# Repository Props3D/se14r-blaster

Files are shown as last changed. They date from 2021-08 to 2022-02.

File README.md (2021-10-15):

## se14r-blaster V0.4 - Prerelease
Product Shot - SE14R

Repository for the Star Wars SE-14r blaster from Props3D. 

Licensed under the Creative Commons - Attribution - Non-Commercial - Share Alike license. https://creativecommons.org/licenses/by-nc-sa/4.0/

***DO NOT SELL OR DISTRIBUTE MODELS OR CODE WITHOUT PERMISSION***

Note that prerelease models have been tested and work, but do not come with instructions or guarantee that everything fits together properly. If you want have feedback please post on our discord(https://discord.gg/NSfZcCfJU6) on the #project-starwars-se14r channel

## Props 3D
* Join the Props3D Discord: https://discord.gg/NSfZcCfJU6
* Follow progress on instagram: https://www.instagram.com/props3dpro/ or https://www.instagram.com/craiggulliver/
* Subscribe on Youtube: https://www.youtube.com/c/Props3D
* Download released designs: https://www.thingiverse.com/props3dpro/designs

## Electonic Components

Electronic | Components
------------ | -------------
Arduino Nano v3 | DF Player Mini with Micro SD Card
Arduino Nano v3 | DF Player Mini + 64mb Micro SD Card
PAM8302A Amp | 7 bit LED - Neopixel
Speaker Amp - PAM8302A | 7 bit LED - Neopixel (circular, NOT the ring)
40mm 2W speaker | 7mm Momentary Switch
40mm 2W speaker | 7mm momentary switch
Mini 360 DC-DC Buck Converter | Lipo 7 4v
Mini 360 DC-DC Buck Converter | Lipo 7.4v
1K Resister | DRV2605L with 8mm ERM
2 X 1K Resister | DRV2605L with 8mm ERM (Optional)

## Parts

* 4x20 pellet gun scope (ebay or aliexpress)
* M5X8mm~12mm Flat X 4 - Grips
* M4X12mm Socket X 2 - Reciever Joiner
* M4X8mm Button X 3 - Scope
* M3X6mm Button X 2 - Haptic Driver
* M3X4~8mm Button X 4 - Battery Cover
* M3X6mm Socket X 3 - Trigger switch / LED
* M3X4~8mm Grub X 5 - BarrelCap / Sight
* M4X6~8mm Grub X 6 - Magazine/Stock Bracket

## Required Libraries
There's are number of libraries that you will need to install using the Arduino Library Manager:
 1. DFPlayerMini_Fast
 2. FastLED
 4. FireTimer
 5. ezButton
 6. Adafruit_DRV2605

## Setup and Configuration
The code can be used by updating the values in config.h based on your components,
wiring, and audio tracks.

```c++   
/** 
 * Enable debug logging:
 *    enabled == 1
 *    disabled == 0
 */
#define ENABLE_DEBUG         0

// Comment out if you want to disable any component
#define ENABLE_EASY_AUDIO            1 //Enable all audio 
#define ENABLE_EASY_BUTTON           1 //Enable all buttons
#define ENABLE_EASY_HAPTIC_2605      1 //Enable haptic driver - disable if using analog
//#define ENABLE_EASY_HAPTIC_ANALOG    1 //Enable analog vibration motors - diable if using driver

// Pin configuration for MP3 Player
#define AUDIO_RX_PIN        5
#define AUDIO_TX_PIN        4

// Pin configuration for all momentary triggers
#define TRIGGER_PIN         3

// Pin for vibration motor digital pin 
#define HAPTIC_PIN          2

// Pin configuration for front barrel WS2812B 7bit LED
#define FIRE_LED_PIN        13
#define FIRE_LED_CNT        7

// track by file index - upload these to the SD card in the correct order
#define TRACK_START_UP        1
#define TRACK_CHANGE_MODE     2
#define TRACK_FIRE_A          3
#define TRACK_FIRE_B          4
#define TRACK_STUN_A          5
#define TRACK_STUN_B          6
#define TRACK_CLIP_RELOAD     7
#define TRACK_CLIP_EMPTY      8
#define TRACK_THEME           9
```

## Audio File Setup
The DF Mini Player will play back both mp3 and wav files. However, the program play
back tracks based on index. The index is determined by the order the files are loaded
onto the card. It also expects all files to be loaded into a sub directory on the card
called "/mp3".

When using a MAC to load files, it will create hidden files that will cause the playback
to seem like it's not working. You'll need to use the terminal window to rm all of these
files and directories from the card.

## Example Wiring Diagram:
SampleWiring

## Test Board Reference Design
SE14r

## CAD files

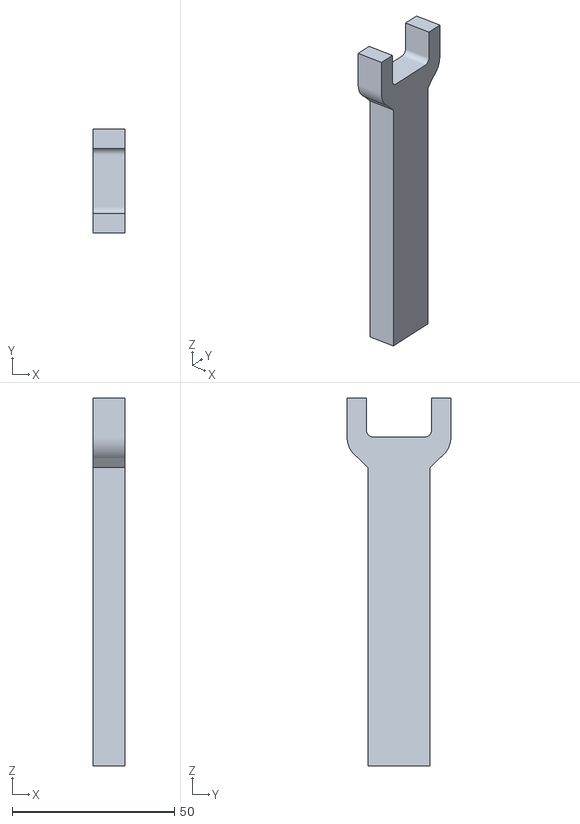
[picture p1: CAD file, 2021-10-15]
models/SE-14r_StandPostBack_V4.stl
10.00 x 32.0 x 113.5

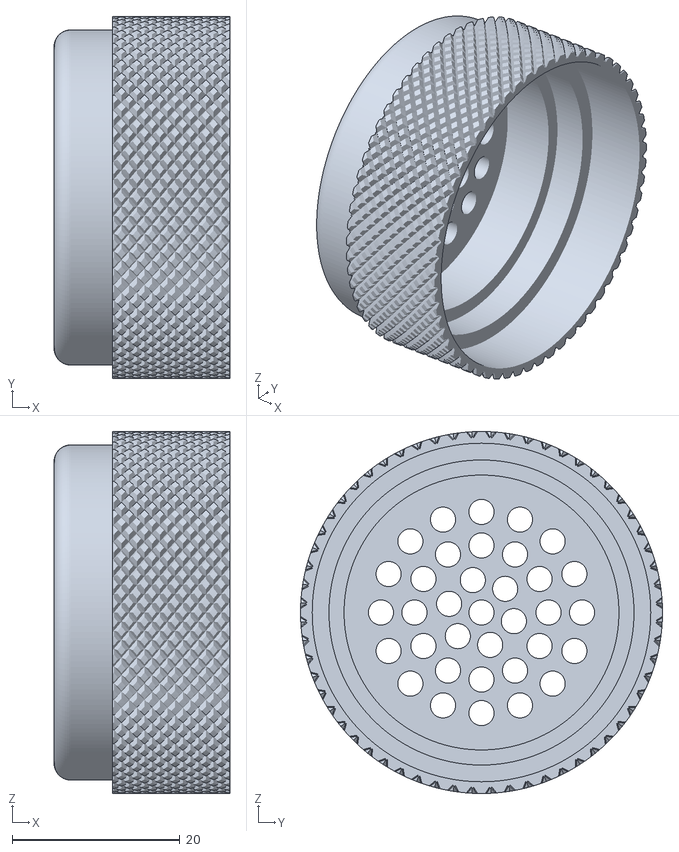
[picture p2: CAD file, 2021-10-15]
models/SE-14r_CapRearOuter_V4.stl
21.0 x 43.2 x 43.2

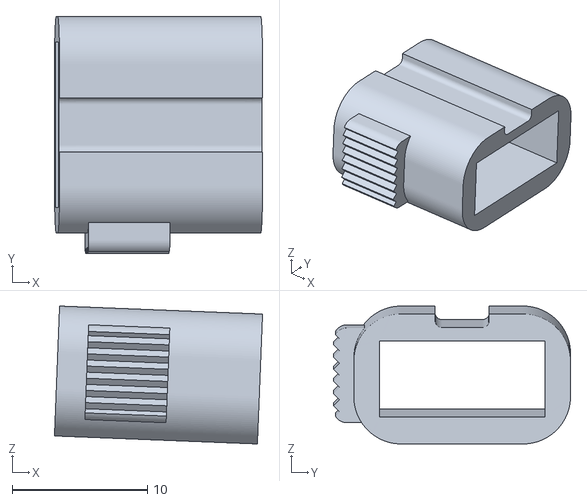
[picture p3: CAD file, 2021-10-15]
models/SE-14r_SightTop_Adjust_V4.stl
15.4 x 17.5 x 10.2

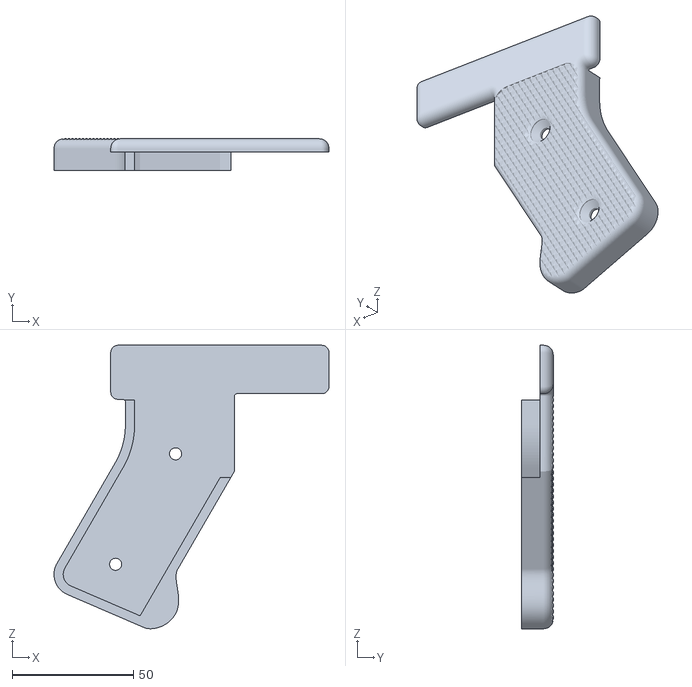
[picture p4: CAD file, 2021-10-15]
models/SE-14r_GripL_V4.stl
113.4 x 13.0 x 116.9

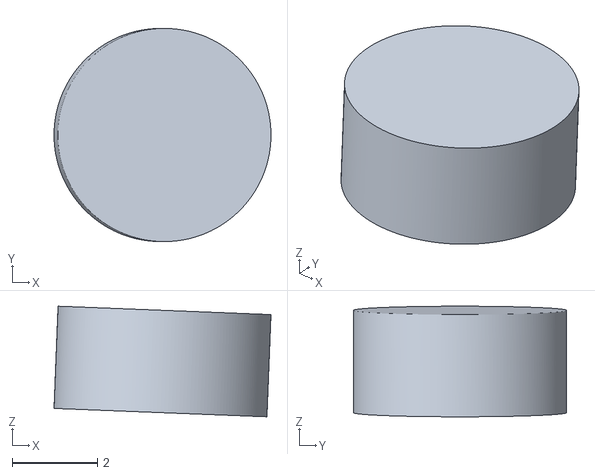
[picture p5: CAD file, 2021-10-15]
models/SE-14r_SightTop_Retainer_V4.stl
5.09 x 5.00 x 2.60

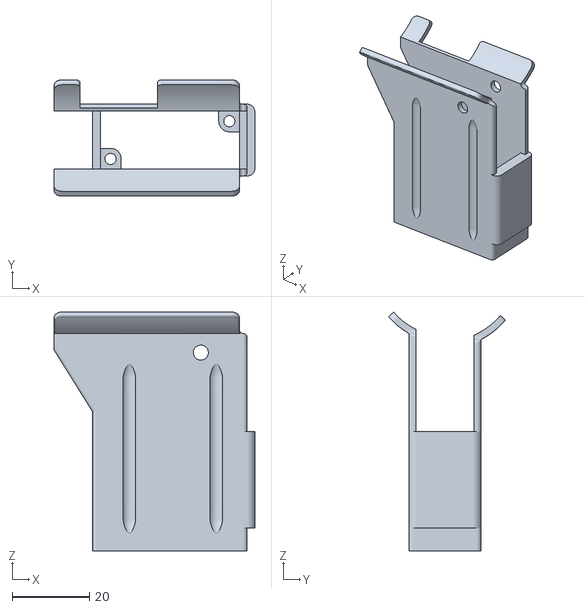
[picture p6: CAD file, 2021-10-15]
models/SE-14r_Magazine_V4.stl
52.0 x 30.1 x 61.9

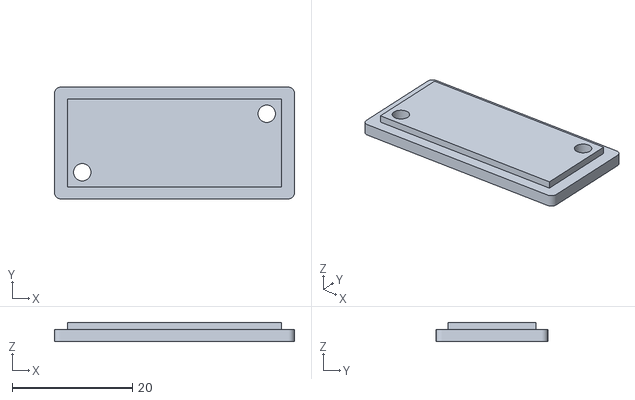
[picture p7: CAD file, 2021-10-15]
models/SE-14r_BatteryCover_V4.stl
40.0 x 18.6 x 3.20

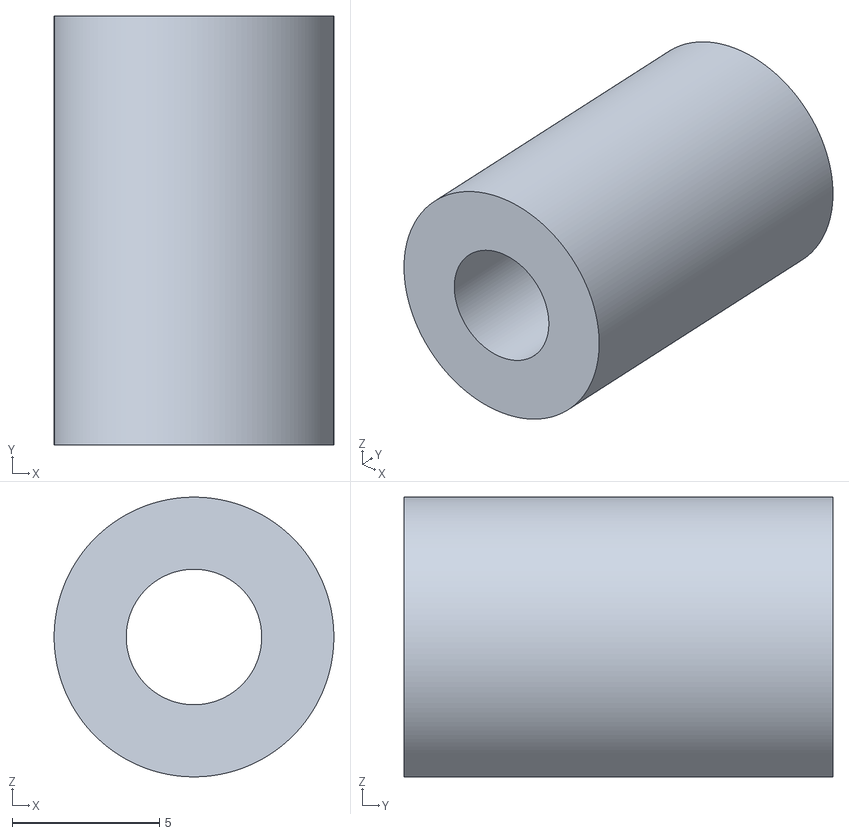
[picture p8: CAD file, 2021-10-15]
models/SE-14r_GripJoiner_V4.stl
9.50 x 14.6 x 9.50

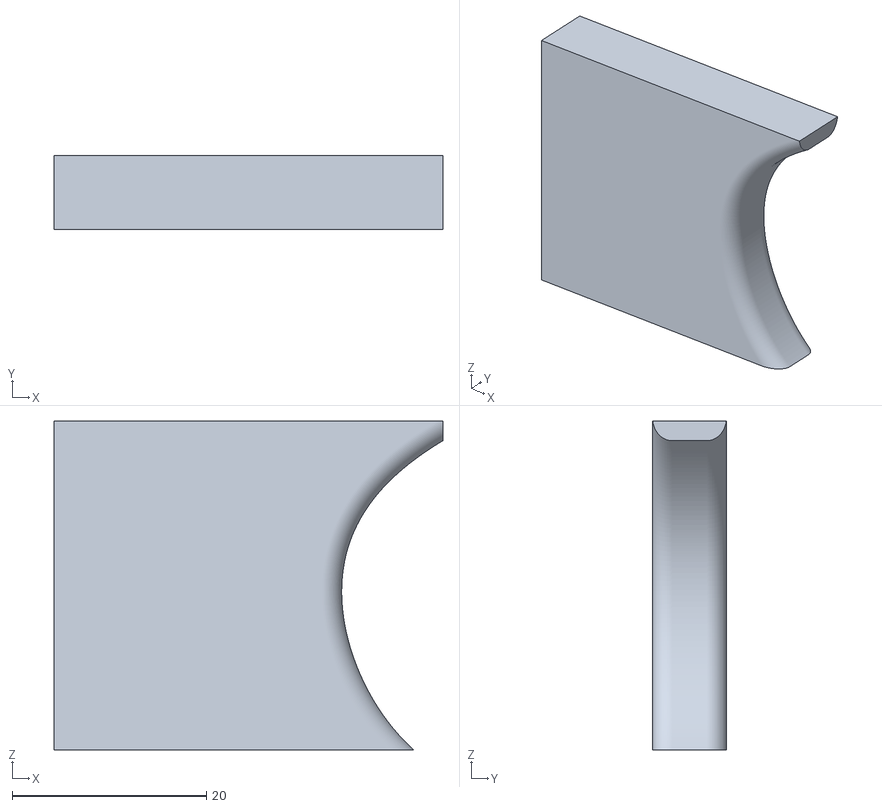
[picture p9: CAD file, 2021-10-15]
models/SE-14r_Trigger_V4.stl
40.0 x 7.60 x 33.8

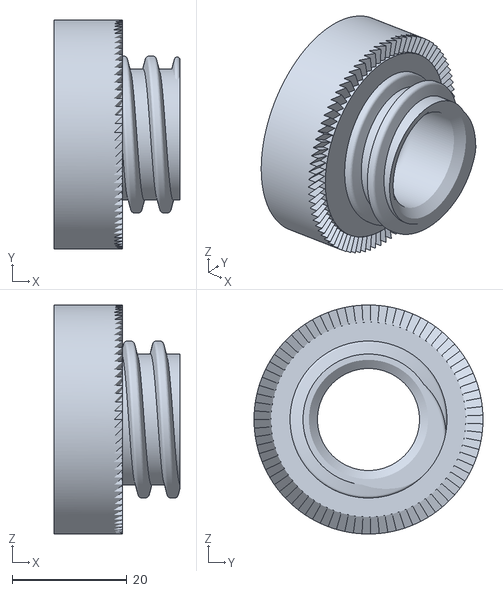
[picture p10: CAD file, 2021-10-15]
models/SE-14r_CapRearInner_V4.stl
22.0 x 40.0 x 40.0

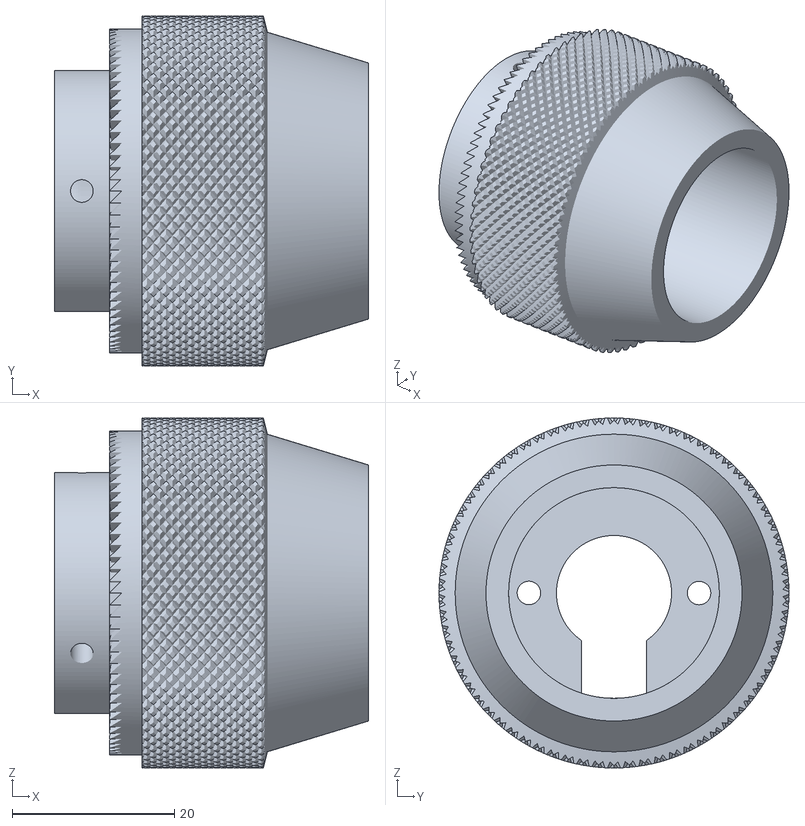
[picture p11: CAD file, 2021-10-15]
models/SE-14r_CapFront_V4.stl
38.8 x 43.2 x 43.2

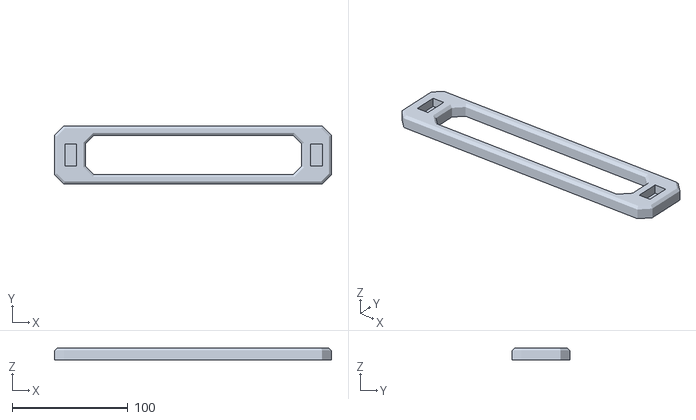
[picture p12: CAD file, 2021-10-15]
models/SE-14r_StandBase_V4.stl
239.6 x 50.0 x 10.0

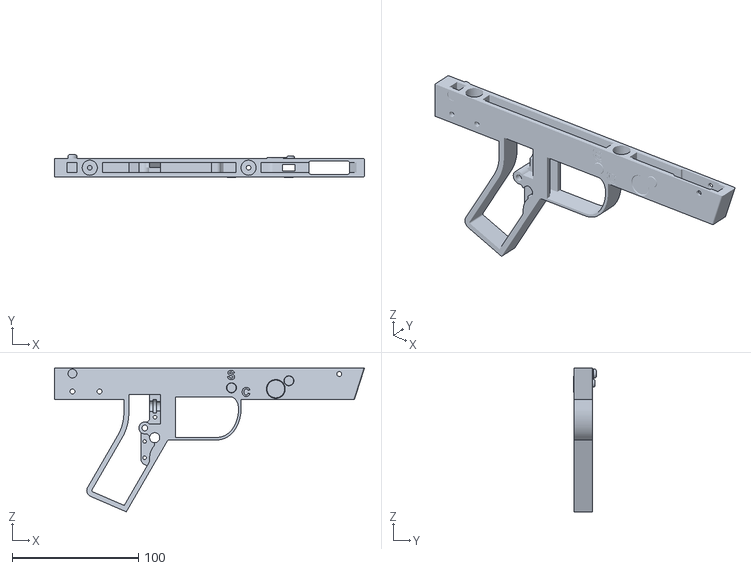
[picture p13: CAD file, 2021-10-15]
models/SE-14r_Lower_V4.stl
246.0 x 17.9 x 114.0

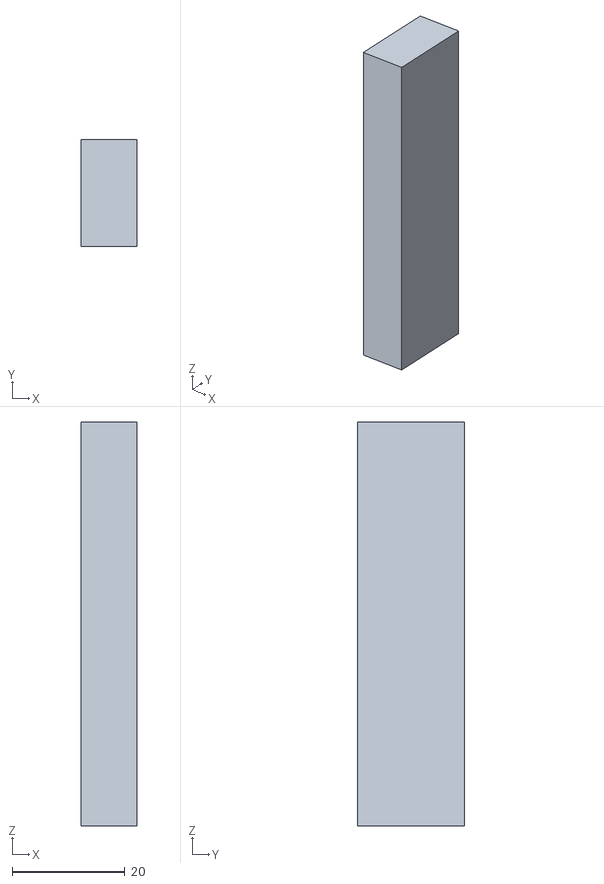
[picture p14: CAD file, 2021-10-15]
models/SE-14r_StandPostFront_V4.stl
10.0 x 19.0 x 71.8

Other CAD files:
models/SE-14r_ScopeMount_V4.stl
models/SE-14r_GripR_V4.stl
models/SE-14r_UpperBack_V4.stl
models/SE-14r_UpperFront_V4.stl
models/SE-14r_BoltHandle_V4.stl
models/SE-14r_Bolt_V4.stl
models/SE-14r_Selector_V4.stl
models/SE-14r_SightBottom_V4.stl
models/SE-14r_SightTop_V4.stl
models/SE-14r_StockBracket_V4.stl
models/SE-14r_SwitchHolder_V4.stl

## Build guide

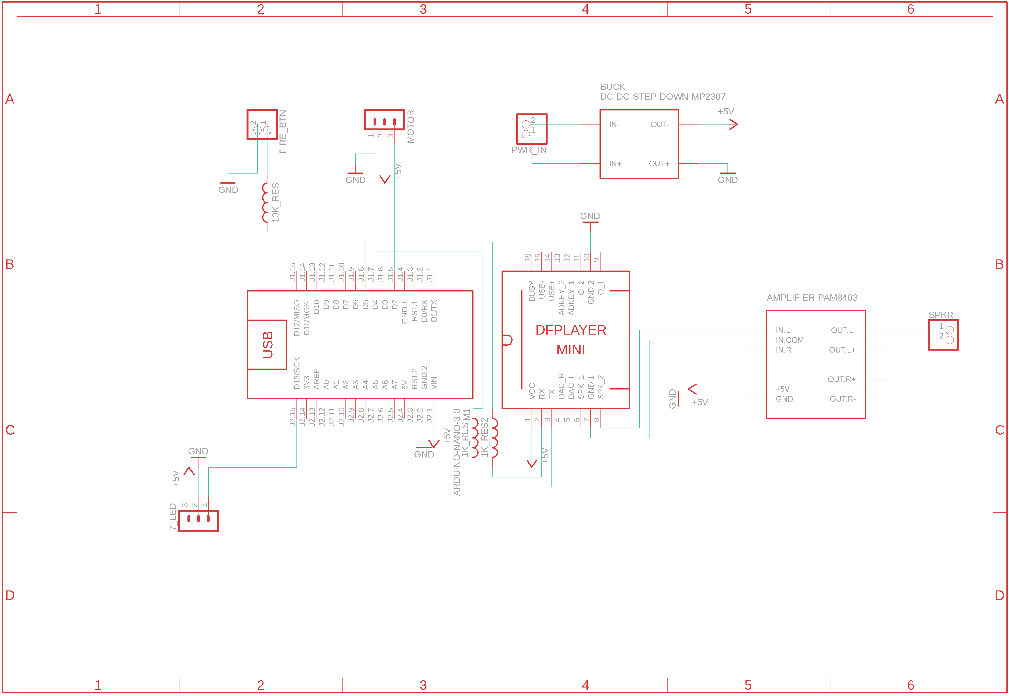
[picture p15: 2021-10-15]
docs/SampleWiring.png

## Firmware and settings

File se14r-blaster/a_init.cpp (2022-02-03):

/*
 * name:  SE-14R
 * Author:  Craig Gulliver
 * Date:  2021-08-28
 * Description: Code for SE-14r blaster setup
 */
#include <Arduino.h>
#include "config.h"
#include "debug.h"
#include "easybutton.h"
#include "easycounter.h"
#include "easyaudio.h"
#include "easyledv3.h"
#include "easyhaptic.h"

/**
 * All components are controlled or enabled by "config.h". Before running, 
 * review and change all configurations based on your setup.
 * 
 * There's no need to change any of the following code or functions. 
 */
EasyAudio audio(AUDIO_RX_PIN, AUDIO_TX_PIN);
EasyButton trigger(TRIGGER_PIN);

EasyLedv3<FIRE_LED_CNT, FIRE_LED_PIN> fireLed;
ezBlasterShot blasterShot(fireLed.RED, fireLed.ORANGE, 4);  // initialize colors to starting fire mode

EasyCounter fireCounter("fire", TRACK_FIRE_ARR, TRACK_CLIP_EMPTY, TRACK_CLIP_RELOAD);
EasyCounter stunCounter("stun", TRACK_STUN_ARR, TRACK_CLIP_EMPTY, TRACK_CLIP_RELOAD);

EasyHaptic haptic;

// trigger mode status
uint8_t selectedTriggerMode   = SELECTOR_FIRE_MODE;   // sets the fire mode to blaster to start

// function declarations
void runAudioPlayback();
void runHapticPlayback();
void runLedDisplay();
void handleFireTrigger();
void handleSelectorMode();
void sendBlasterPulse(EasyCounter &counter);
EasyCounter& getTriggerCounter();

void setup () {
  Serial.begin (9600);
  debugLog("Starting setup");
  // set up the fire trigger and the debounce threshold
  trigger.begin(25);

  //initializes the audio player and sets the volume
  audio.begin(20);

  // initialize all the leds
  // initialize the trigger led and set brightness
  fireLed.begin(75);

  // Initialize the clip counters for different modes
  fireCounter.begin(0, 10, COUNTER_MODE_DOWN);
  stunCounter.begin(0, 10, COUNTER_MODE_DOWN);

  // init the haptic ERM motors
  haptic.begin();

  // queue the first track
  debugLog("Powering up");
  audio.queuePlayback(TRACK_START_UP);
}

/**
 * The main loop.
 */
void loop () {
  // always handle the activated components first, before processing new inputs
  runHapticPlayback();
  runAudioPlayback();
  runLedDisplay();
  // check for new inputs
  handleFireTrigger();
}

/**
 * Run the haptic motor pattern
 */
void runHapticPlayback() {
  haptic.updateMotor();
}
/**
 * Playback the next queued track
 */
void runAudioPlayback() {
  audio.playQueuedTrack();
}
/**
 * Run the led pattern
 */
void runLedDisplay() {
  fireLed.updateDisplay();
}

/**
 * Checks the fire trigger momentary switch.
 * Short press should send an alternating blaster pulse
 * Long press should change modes between A/B and C/D
 */
void handleFireTrigger() {
  // check trigger button
  int buttonStateFire = trigger.checkState();
  // check if a trigger is pressed.
  if (buttonStateFire == BUTTON_SHORT_PRESS) {
      sendBlasterPulse(getTriggerCounter());
  }
  if (buttonStateFire == BUTTON_LONG_PRESS) {
    handleSelectorMode();
  }
}

/**
 * Sends a blaster pulse.
 *   1. Toggles a clip counter
 *   2. Checks for an empty clip 
 *   3. If clip is not empty
 *      a. play audio track
 *      b. update led strip
 *      c. update led counter to the current clip counter
 *   4. Otherwise play empty clip track
 *
 */
void sendBlasterPulse(EasyCounter &counter) {
  debugLog("send alternating blaster pulse");
  bool emptyClip = counter.isEmpty();
  bool fullClip = counter.isFull();
  // check the track number before ticking, in case it's the last round
  // alternate between two firing blasts
  uint8_t idx = counter.getCount() % 2;
  int track = counter.getTrackNumber(idx); // returns the approapriate track, or empty clip
  counter.tick();
  if (fullClip)
    track = counter.getTrackNumber(idx);   // We redo this when the clip is full to get the right track
  audio.queuePlayback(track);
  if (emptyClip == false) {
    fireLed.activate(blasterShot);
    haptic.activate();
  }
}

EasyCounter& getTriggerCounter() {
  if (selectedTriggerMode == SELECTOR_FIRE_MODE)
      return fireCounter;
  return stunCounter;
}

/**
 * Checks the selector mode momentary switch.
 * 1. if a long preess plackback the theme track
 * 2. If a short press
 *   a. playback changee mode track
 *   b. toggle fire mode
 */
void handleSelectorMode() {
  // Check for Switching modes
  if (selectedTriggerMode == SELECTOR_FIRE_MODE) {
    selectedTriggerMode = SELECTOR_STUN_MODE;
    blasterShot.initialize(fireLed.YELLOW, fireLed.WHITE);  // shot - flash with color fade
    debugLog("Stun Mode selected");
  } else {
    selectedTriggerMode = SELECTOR_FIRE_MODE;
    blasterShot.initialize(fireLed.RED, fireLed.ORANGE);  // shot - flash with color fade
    debugLog("Fire Mode selected");
  }
  audio.queuePlayback(TRACK_CHANGE_MODE);
}

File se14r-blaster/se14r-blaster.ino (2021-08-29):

/**
 * This is the main file for the SE-14R blaster setup.
 * 
 * Hardware setup:
 *  - 40mm speaker in rear cap
 *  - arduino nano in the receiver
 *  - DF mini player and amp in handle
 *  - 7mm momentary switch in the handle
 *  - sliding on/aff switch in front of receiver
 *  - 7.4v lipo battery and buck convertere in the mag
 *  - 7LED Array in front, need lens
 *  Optional hardware considerations:
 *  - Lever switch reload in the front barrel
 *  - Haptic vibration motors in grip
 * 
 * All components settings can be found in "config.h". Before running, 
 * review and change all configurations based on your setup.
 * 
 * There's are number of libraries that you will need to install using the 
 * Library Manager:
 * 1. DFPlayerMini_Fast
 * 2. FastLED
 * 4. FireTimer
 * 5. ezButton
 * 6. Adafruit_DRV2605
 * 
 * The main loop:
 * 1. Check audio queue for playback
 * 2. Check if the haptic motors have been activated
 *   a. play the script
 * 3. Check if the leds have been activated
 *   a. update the leds following the pattern that has been set
 * 4. Check the fire trigger momentary switch.
 * 5. Send a blaster pulse, if fire trigger is a short press
 *   a. Toggles a clip counter
 *   b. Checks for an empty clip 
 *   c. If clip is not empty
 *      i. play alternating audio tracks for different sounds 
 *     ii. activate front led with blaster shot
 *         1. Flash white
 *         2. Burn Red to orange, then fade as it cools
 *   d. Otherwise play empty clip track
 * 6. Changes mode, if fire trigger is a long press
 *     i. playback change mode track
 *    ii. toggle fire mode
 * 
 */
 

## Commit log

2021-10-14 adding support for analog vibration motor
    [a_init.cpp, config.h]
2021-10-15 adding wiring diagram
